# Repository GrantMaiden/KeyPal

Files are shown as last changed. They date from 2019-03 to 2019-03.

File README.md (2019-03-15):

KeyPal is A project I worked with during my undergrad alongside my teammates, Dane Le, Justin Warner, and Spencer Anderson.

I was the only EE working on the project, so my main duties were to develop the schematic and PCB for the group. I also developed the MCU application, and took care of component selection as well as analyzed and timing constraints on the system.

KeyPal is a fun solution to helping teach a new typist the ins and outs of proper keyboard hand placement.
It has capacitive sensors in the homerow of the keyboard, to make sure that proper hand placement is intact during typing, as well as multicolor LEDs under every key on the keyboard. These light up to aid the typist in learning the keypositions while using the peripheral typing trainer application, which is written in python.

________________________________________________________________________________________________________________________

Schematic creation, PCB layout, component selection, MCU design, C/C++, Python, timing analysis, Communication Protocols (i2c, USB),  capacitive touch.

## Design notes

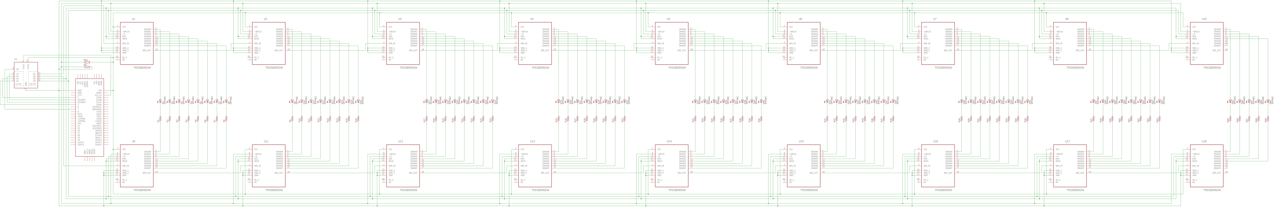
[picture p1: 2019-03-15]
Eagle/Projects/Keyboard PCB/Keyboard schematic.png

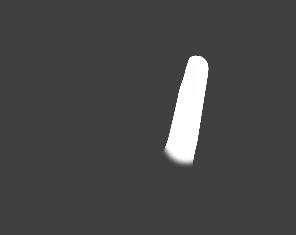
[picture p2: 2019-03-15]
Final/resources/finger_3.png

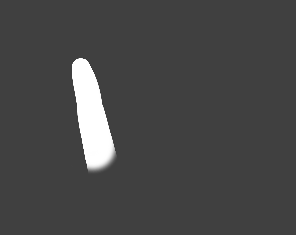
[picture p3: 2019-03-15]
Final/resources/finger_1.png

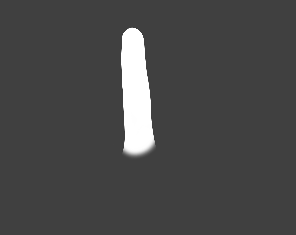
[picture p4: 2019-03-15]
Final/resources/finger_2.png

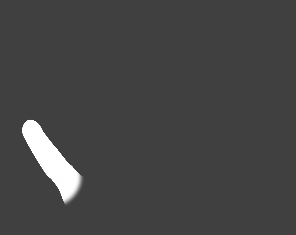
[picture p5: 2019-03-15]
Final/resources/finger_0.png

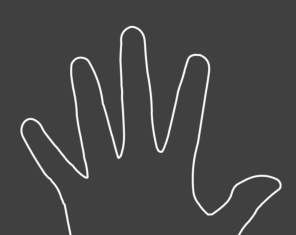
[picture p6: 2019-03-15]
Final/resources/hand_outline.png

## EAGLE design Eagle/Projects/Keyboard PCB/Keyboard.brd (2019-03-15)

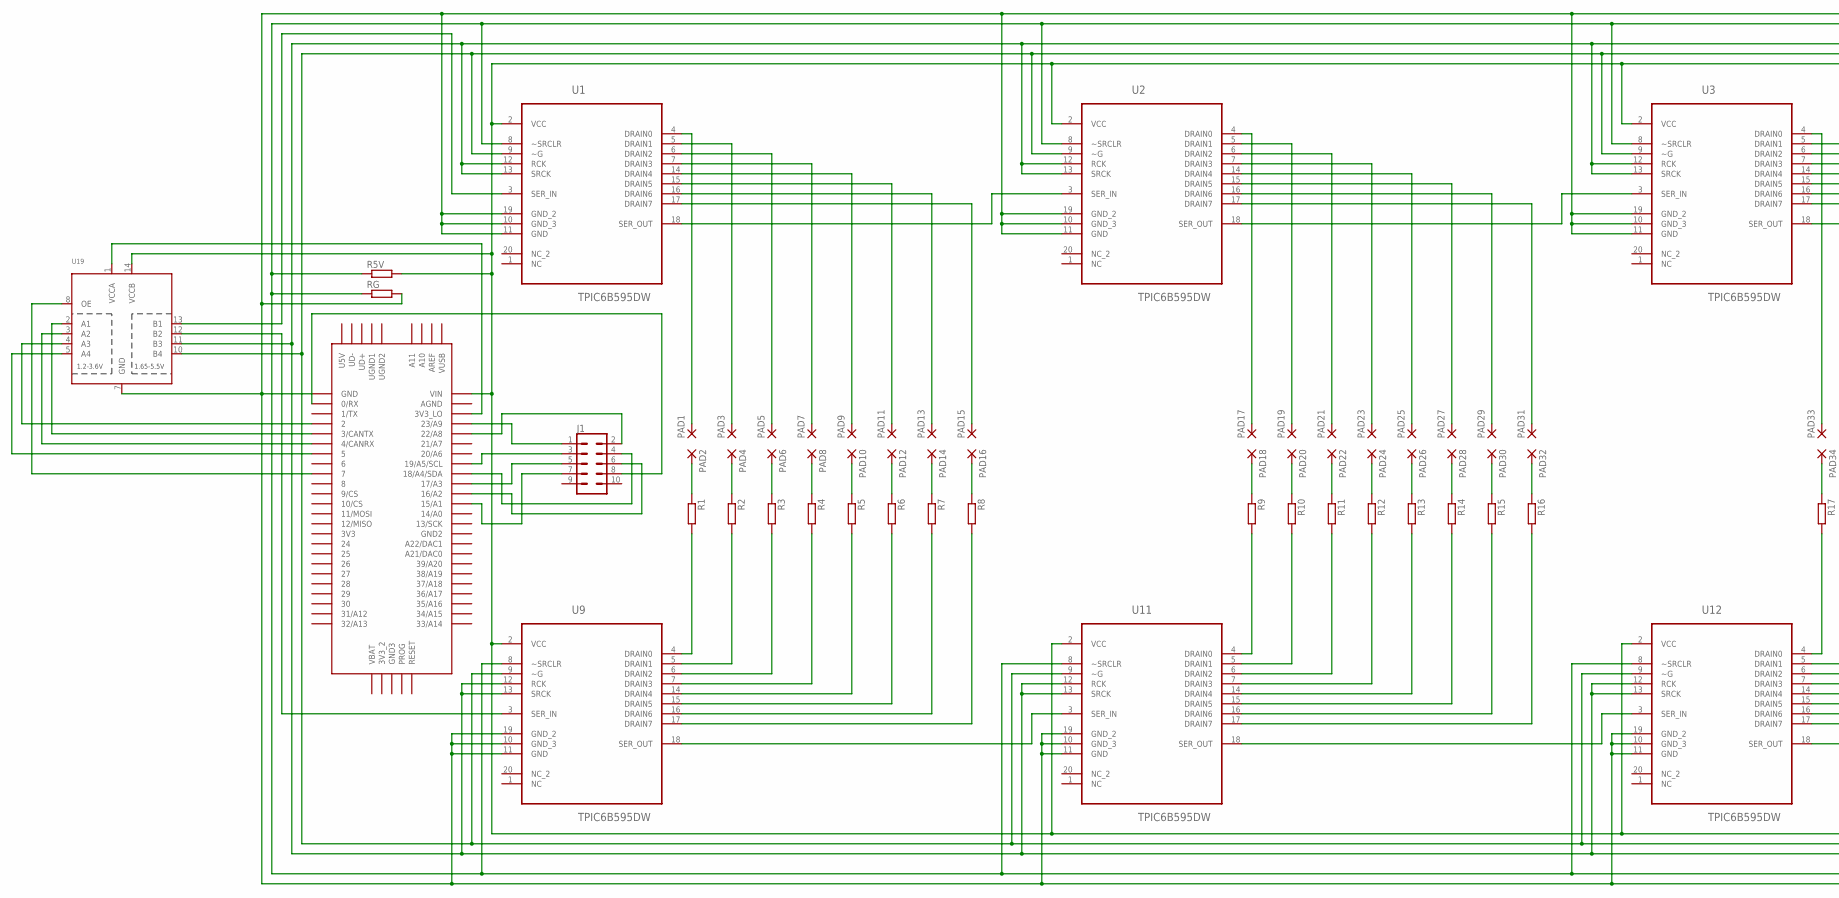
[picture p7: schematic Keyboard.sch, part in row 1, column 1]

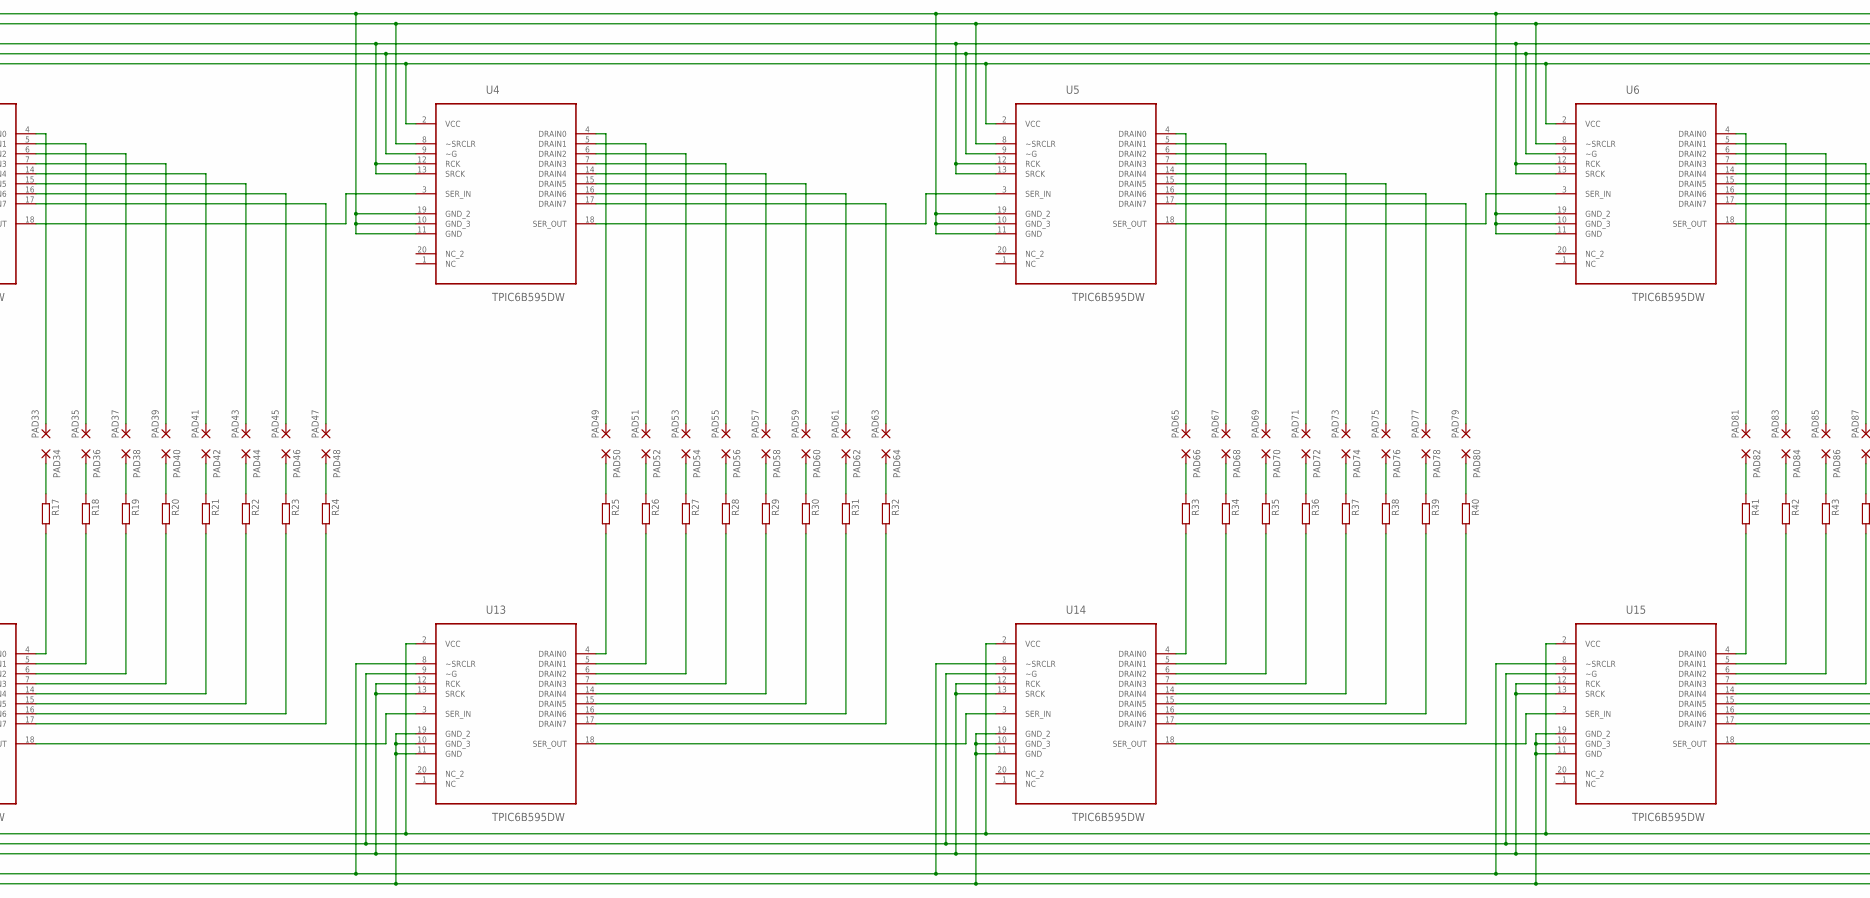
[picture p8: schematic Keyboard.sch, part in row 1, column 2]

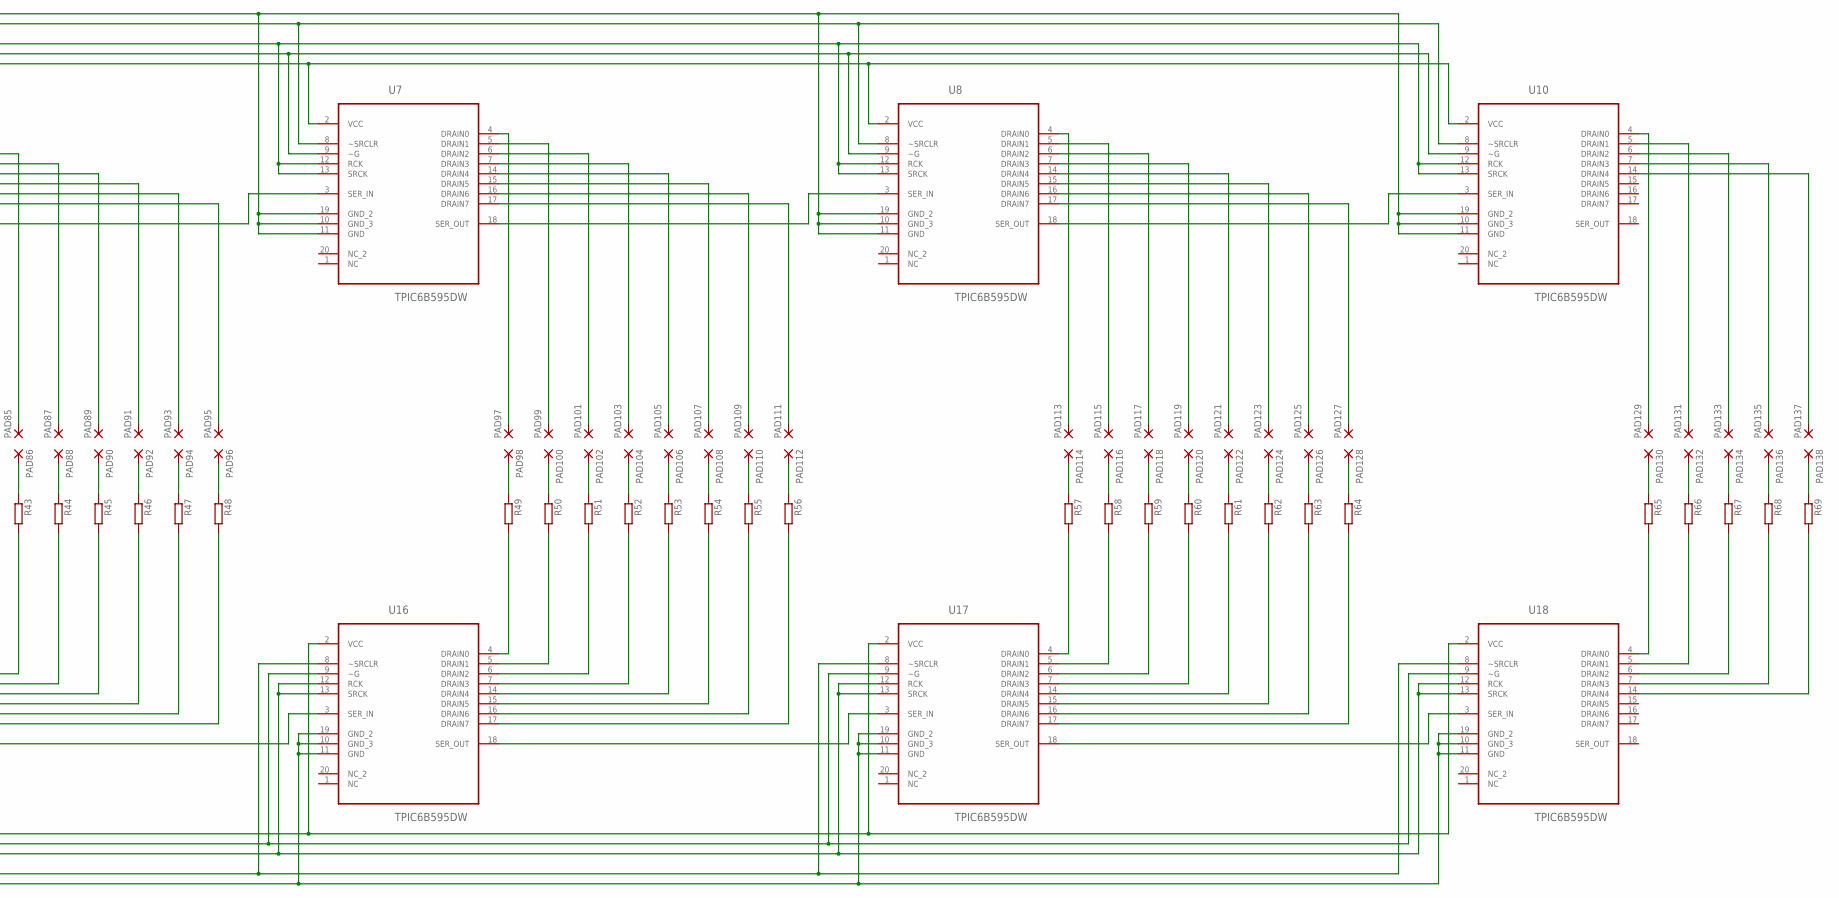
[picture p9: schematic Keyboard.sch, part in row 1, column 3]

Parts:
J1: CONN_05X2SHD; 2X5-SHROUDED
PAD1, PAD2, PAD3, PAD4, PAD5, PAD6, PAD7, PAD8, PAD9, PAD10, PAD11, PAD12, PAD13, PAD14, PAD15, PAD16, PAD17, PAD18, PAD19, PAD20, PAD21, PAD22, PAD23, PAD24, PAD25, PAD26, PAD27, PAD28, PAD29, PAD30, PAD31, PAD32, PAD33, PAD34, PAD35, PAD36, PAD37, PAD38, PAD39, PAD40, PAD41, PAD42, PAD43, PAD44, PAD45, PAD46, PAD47, PAD48, PAD49, PAD50, PAD51, PAD52, PAD53, PAD54, PAD55, PAD56, PAD57, PAD58, PAD59, PAD60, PAD61, PAD62, PAD63, PAD64, PAD65, PAD66, PAD67, PAD68, PAD69, PAD70, PAD71, PAD72, PAD73, PAD74, PAD75, PAD76, PAD77, PAD78, PAD79, PAD80, PAD81, PAD82, PAD83, PAD84, PAD85, PAD86, PAD87, PAD88, PAD89, PAD90, PAD91, PAD92, PAD93, PAD94, PAD95, PAD96, PAD97, PAD98, PAD99, PAD100, PAD101, PAD102, PAD103, PAD104, PAD105, PAD106, PAD107, PAD108, PAD109, PAD110, PAD111, PAD112, PAD113, PAD114, PAD115, PAD116, PAD117, PAD118, PAD119, PAD120, PAD121, PAD122, PAD123, PAD124, PAD125, PAD126, PAD127, PAD128, PAD129, PAD130, PAD131, PAD132, PAD133, PAD134, PAD135, PAD136, PAD137, PAD138: 1,6/0,8
R1, R2, R3, R4, R5, R5V, R6, R7, R8, R9, R10, R11, R12, R13, R14, R15, R16, R17, R18, R19, R20, R21, R22, R23, R24, R25, R26, R27, R28, R29, R30, R31, R32, R33, R34, R35, R36, R37, R38, R39, R40, R41, R42, R43, R44, R45, R46, R47, R48, R49, R50, R51, R52, R53, R54, R55, R56, R57, R58, R59, R60, R61, R62, R63, R64, R65, R66, R67, R68, R69: R; R0805
RG: R; R0805
U1, U2, U3, U4, U5, U6, U7, U8, U9, U10, U11, U12, U13, U14, U15, U16, U17, U18: TPIC6B595DW; SOIC127P1030X265-20N
U19: TXB0104PWRSOIC14; SO14
U$59: TEENSY_3.5/3.6

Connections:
unnamed: PAD2.1, R1.1
unnamed: U1.18 (SER_OUT), U2.3 (SER_IN)
unnamed: U1.12 (RCK), U1.13 (SRCK), U2.12 (RCK), U2.13 (SRCK), U3.12 (RCK), U3.13 (SRCK), U4.12 (RCK), U4.13 (SRCK), U5.12 (RCK), U5.13 (SRCK), U6.12 (RCK), U6.13 (SRCK), U7.12 (RCK), U7.13 (SRCK), U8.12 (RCK), U8.13 (SRCK), U9.12 (RCK), U9.13 (SRCK), U10.12 (RCK), U10.13 (SRCK), U11.12 (RCK), U11.13 (SRCK), U12.12 (RCK), U12.13 (SRCK), U13.12 (RCK), U13.13 (SRCK), U14.12 (RCK), U14.13 (SRCK), U15.12 (RCK), U15.13 (SRCK), U16.12 (RCK), U16.13 (SRCK), U17.12 (RCK), U17.13 (SRCK), U18.12 (RCK), U18.13 (SRCK), U19.11 (B3)
unnamed: PAD4.1, R2.1
unnamed: PAD6.1, R3.1
unnamed: PAD8.1, R4.1
unnamed: PAD10.1, R5.1
unnamed: PAD12.1, R6.1
unnamed: PAD14.1, R7.1
unnamed: PAD16.1, R8.1
unnamed: PAD18.1, R9.1
unnamed: U1.9 (~G), U2.9 (~G), U3.9 (~G), U4.9 (~G), U5.9 (~G), U6.9 (~G), U7.9 (~G), U8.9 (~G), U9.9 (~G), U10.9 (~G), U11.9 (~G), U12.9 (~G), U13.9 (~G), U14.9 (~G), U15.9 (~G), U16.9 (~G), U17.9 (~G), U18.9 (~G), U19.10 (B4)
unnamed: PAD20.1, R10.1
unnamed: PAD22.1, R11.1
unnamed: PAD24.1, R12.1
unnamed: PAD26.1, R13.1
unnamed: PAD28.1, R14.1
unnamed: PAD30.1, R15.1
unnamed: PAD32.1, R16.1
unnamed: PAD34.1, R17.1
unnamed: PAD36.1, R18.1
unnamed: PAD38.1, R19.1
unnamed: PAD40.1, R20.1
unnamed: PAD42.1, R21.1
unnamed: PAD44.1, R22.1
unnamed: PAD46.1, R23.1
unnamed: PAD48.1, R24.1
unnamed: PAD50.1, R25.1
unnamed: PAD52.1, R26.1
unnamed: PAD54.1, R27.1
unnamed: PAD56.1, R28.1
unnamed: PAD58.1, R29.1
unnamed: PAD60.1, R30.1
unnamed: PAD62.1, R31.1
unnamed: PAD64.1, R32.1
unnamed: PAD66.1, R33.1
unnamed: PAD68.1, R34.1
unnamed: PAD70.1, R35.1
unnamed: PAD72.1, R36.1
unnamed: PAD74.1, R37.1
unnamed: PAD76.1, R38.1
unnamed: PAD78.1, R39.1
unnamed: PAD80.1, R40.1
unnamed: PAD82.1, R41.1
unnamed: PAD84.1, R42.1
unnamed: PAD86.1, R43.1
unnamed: PAD88.1, R44.1
unnamed: PAD90.1, R45.1
unnamed: PAD92.1, R46.1
unnamed: PAD94.1, R47.1
unnamed: PAD96.1, R48.1
unnamed: PAD98.1, R49.1
unnamed: PAD100.1, R50.1
unnamed: PAD102.1, R51.1
unnamed: PAD104.1, R52.1
unnamed: PAD106.1, R53.1
unnamed: PAD108.1, R54.1
unnamed: PAD110.1, R55.1
unnamed: PAD112.1, R56.1
unnamed: PAD114.1, R57.1
unnamed: R5V.2, U1.2 (VCC), U2.2 (VCC), U3.2 (VCC), U4.2 (VCC), U5.2 (VCC), U6.2 (VCC), U7.2 (VCC), U8.2 (VCC), U9.2 (VCC), U10.2 (VCC), U11.2 (VCC), U12.2 (VCC), U13.2 (VCC), U14.2 (VCC), U15.2 (VCC), U16.2 (VCC), U17.2 (VCC), U18.2 (VCC), U19.14 (VCCB), U$59.VIN
unnamed: U19.4 (A3), U$59.2
unnamed: R5V.1, RG.1, U1.8 (~SRCLR), U2.8 (~SRCLR), U3.8 (~SRCLR), U4.8 (~SRCLR), U5.8 (~SRCLR), U6.8 (~SRCLR), U7.8 (~SRCLR), U8.8 (~SRCLR), U9.8 (~SRCLR), U10.8 (~SRCLR), U11.8 (~SRCLR), U12.8 (~SRCLR), U13.8 (~SRCLR), U14.8 (~SRCLR), U15.8 (~SRCLR), U16.8 (~SRCLR), U17.8 (~SRCLR), U18.8 (~SRCLR)
unnamed: U1.3 (SER_IN), U19.13 (B1)
unnamed: U2.18 (SER_OUT), U3.3 (SER_IN)
unnamed: R68.2, U18.7 (DRAIN3)
unnamed: R69.2, U18.14 (DRAIN4)
unnamed: PAD129.1, U10.4 (DRAIN0)
unnamed: PAD131.1, U10.5 (DRAIN1)
unnamed: U3.18 (SER_OUT), U4.3 (SER_IN)
unnamed: U4.18 (SER_OUT), U5.3 (SER_IN)
unnamed: U5.18 (SER_OUT), U6.3 (SER_IN)
unnamed: U6.18 (SER_OUT), U7.3 (SER_IN)
unnamed: U7.18 (SER_OUT), U8.3 (SER_IN)
unnamed: U8.18 (SER_OUT), U10.3 (SER_IN)
unnamed: U19.1 (VCCA), U$59.3V3_LO
unnamed: U19.2 (A1), U$59.3/CANTX
unnamed: U9.3 (SER_IN), U19.12 (B2)
unnamed: U19.8 (OE), U$59.7
unnamed: PAD116.1, R58.1
unnamed: PAD118.1, R59.1
unnamed: PAD120.1, R60.1
unnamed: PAD122.1, R61.1
unnamed: PAD124.1, R62.1
unnamed: PAD126.1, R63.1
unnamed: PAD128.1, R64.1
unnamed: U9.18 (SER_OUT), U11.3 (SER_IN)
unnamed: U11.18 (SER_OUT), U12.3 (SER_IN)
unnamed: U12.18 (SER_OUT), U13.3 (SER_IN)
unnamed: U13.18 (SER_OUT), U14.3 (SER_IN)
unnamed: U14.18 (SER_OUT), U15.3 (SER_IN)
unnamed: U15.18 (SER_OUT), U16.3 (SER_IN)
unnamed: U16.18 (SER_OUT), U17.3 (SER_IN)
unnamed: U17.18 (SER_OUT), U18.3 (SER_IN)
unnamed: RG.2, U1.10 (GND_3), U1.11 (GND), U1.19 (GND_2), U2.10 (GND_3), U2.11 (GND), U2.19 (GND_2), U3.10 (GND_3), U3.11 (GND), U3.19 (GND_2), U4.10 (GND_3), U4.11 (GND), U4.19 (GND_2), U5.10 (GND_3), U5.11 (GND), U5.19 (GND_2), U6.10 (GND_3), U6.11 (GND), U6.19 (GND_2), U7.10 (GND_3), U7.11 (GND), U7.19 (GND_2), U8.10 (GND_3), U8.11 (GND), U8.19 (GND_2), U9.10 (GND_3), U9.11 (GND), U9.19 (GND_2), U10.10 (GND_3), U10.11 (GND), U10.19 (GND_2), U11.10 (GND_3), U11.11 (GND), U11.19 (GND_2), U12.10 (GND_3), U12.11 (GND), U12.19 (GND_2), U13.10 (GND_3), U13.11 (GND), U13.19 (GND_2), U14.10 (GND_3), U14.11 (GND), U14.19 (GND_2), U15.10 (GND_3), U15.11 (GND), U15.19 (GND_2), U16.10 (GND_3), U16.11 (GND), U16.19 (GND_2), U17.10 (GND_3), U17.11 (GND), U17.19 (GND_2), U18.10 (GND_3), U18.11 (GND), U18.19 (GND_2), U19.7 (GND), U$59.GND
unnamed: U19.5 (A4), U$59.5
unnamed: PAD130.1, R65.1
unnamed: PAD1.1, U1.4 (DRAIN0)
unnamed: PAD3.1, U1.5 (DRAIN1)
unnamed: PAD5.1, U1.6 (DRAIN2)
unnamed: PAD7.1, U1.7 (DRAIN3)
unnamed: PAD9.1, U1.14 (DRAIN4)
unnamed: PAD11.1, U1.15 (DRAIN5)
unnamed: PAD13.1, U1.16 (DRAIN6)
unnamed: PAD15.1, U1.17 (DRAIN7)
unnamed: R1.2, U9.4 (DRAIN0)
unnamed: R2.2, U9.5 (DRAIN1)
unnamed: R3.2, U9.6 (DRAIN2)
unnamed: R4.2, U9.7 (DRAIN3)
unnamed: R5.2, U9.14 (DRAIN4)
unnamed: R6.2, U9.15 (DRAIN5)
unnamed: R7.2, U9.16 (DRAIN6)
unnamed: R8.2, U9.17 (DRAIN7)
unnamed: R9.2, U11.4 (DRAIN0)
unnamed: R10.2, U11.5 (DRAIN1)
unnamed: R11.2, U11.6 (DRAIN2)
unnamed: R12.2, U11.7 (DRAIN3)
unnamed: R13.2, U11.14 (DRAIN4)
unnamed: R14.2, U11.15 (DRAIN5)
unnamed: R15.2, U11.16 (DRAIN6)
unnamed: R16.2, U11.17 (DRAIN7)
unnamed: PAD17.1, U2.4 (DRAIN0)
unnamed: PAD19.1, U2.5 (DRAIN1)
unnamed: PAD21.1, U2.6 (DRAIN2)
unnamed: PAD23.1, U2.7 (DRAIN3)
unnamed: PAD25.1, U2.14 (DRAIN4)
unnamed: PAD27.1, U2.15 (DRAIN5)
unnamed: PAD29.1, U2.16 (DRAIN6)
unnamed: PAD31.1, U2.17 (DRAIN7)
unnamed: PAD33.1, U3.4 (DRAIN0)
unnamed: PAD35.1, U3.5 (DRAIN1)
unnamed: PAD37.1, U3.6 (DRAIN2)
unnamed: PAD39.1, U3.7 (DRAIN3)
unnamed: PAD41.1, U3.14 (DRAIN4)
unnamed: PAD43.1, U3.15 (DRAIN5)
unnamed: PAD45.1, U3.16 (DRAIN6)
unnamed: PAD47.1, U3.17 (DRAIN7)
unnamed: R17.2, U12.4 (DRAIN0)
unnamed: R18.2, U12.5 (DRAIN1)
unnamed: R19.2, U12.6 (DRAIN2)
unnamed: R20.2, U12.7 (DRAIN3)
unnamed: R21.2, U12.14 (DRAIN4)
unnamed: R22.2, U12.15 (DRAIN5)
unnamed: R23.2, U12.16 (DRAIN6)
unnamed: R24.2, U12.17 (DRAIN7)
unnamed: R25.2, U13.4 (DRAIN0)
unnamed: R26.2, U13.5 (DRAIN1)
unnamed: R27.2, U13.6 (DRAIN2)
unnamed: U19.3 (A2), U$59.4/CANRX
unnamed: R28.2, U13.7 (DRAIN3)
unnamed: R29.2, U13.14 (DRAIN4)
unnamed: R30.2, U13.15 (DRAIN5)
unnamed: R31.2, U13.16 (DRAIN6)
unnamed: R32.2, U13.17 (DRAIN7)
unnamed: PAD49.1, U4.4 (DRAIN0)
unnamed: PAD51.1, U4.5 (DRAIN1)
unnamed: PAD53.1, U4.6 (DRAIN2)
unnamed: PAD55.1, U4.7 (DRAIN3)
unnamed: PAD57.1, U4.14 (DRAIN4)
unnamed: PAD59.1, U4.15 (DRAIN5)
unnamed: PAD61.1, U4.16 (DRAIN6)
unnamed: PAD63.1, U4.17 (DRAIN7)
unnamed: PAD65.1, U5.4 (DRAIN0)
unnamed: PAD67.1, U5.5 (DRAIN1)
unnamed: PAD69.1, U5.6 (DRAIN2)
unnamed: PAD71.1, U5.7 (DRAIN3)
unnamed: PAD73.1, U5.14 (DRAIN4)
unnamed: PAD75.1, U5.15 (DRAIN5)
unnamed: PAD77.1, U5.16 (DRAIN6)
unnamed: PAD79.1, U5.17 (DRAIN7)
unnamed: R33.2, U14.4 (DRAIN0)
unnamed: R34.2, U14.5 (DRAIN1)
unnamed: R35.2, U14.6 (DRAIN2)
unnamed: R36.2, U14.7 (DRAIN3)
unnamed: R37.2, U14.14 (DRAIN4)
unnamed: R38.2, U14.15 (DRAIN5)
unnamed: R39.2, U14.16 (DRAIN6)
unnamed: R40.2, U14.17 (DRAIN7)
unnamed: R41.2, U15.4 (DRAIN0)
unnamed: R42.2, U15.5 (DRAIN1)
unnamed: R43.2, U15.6 (DRAIN2)
unnamed: R44.2, U15.7 (DRAIN3)
unnamed: R45.2, U15.14 (DRAIN4)
unnamed: R46.2, U15.15 (DRAIN5)
unnamed: R47.2, U15.16 (DRAIN6)
unnamed: R48.2, U15.17 (DRAIN7)
unnamed: PAD81.1, U6.4 (DRAIN0)
unnamed: PAD83.1, U6.5 (DRAIN1)
unnamed: PAD85.1, U6.6 (DRAIN2)
unnamed: PAD87.1, U6.7 (DRAIN3)
unnamed: PAD89.1, U6.14 (DRAIN4)
unnamed: PAD91.1, U6.15 (DRAIN5)
unnamed: PAD93.1, U6.16 (DRAIN6)
unnamed: PAD95.1, U6.17 (DRAIN7)
unnamed: R49.2, U16.4 (DRAIN0)
unnamed: R50.2, U16.5 (DRAIN1)
unnamed: R51.2, U16.6 (DRAIN2)
unnamed: R52.2, U16.7 (DRAIN3)
unnamed: R53.2, U16.14 (DRAIN4)
unnamed: R54.2, U16.15 (DRAIN5)
unnamed: R55.2, U16.16 (DRAIN6)
unnamed: R56.2, U16.17 (DRAIN7)
unnamed: PAD97.1, U7.4 (DRAIN0)
unnamed: PAD99.1, U7.5 (DRAIN1)
unnamed: PAD101.1, U7.6 (DRAIN2)
unnamed: PAD103.1, U7.7 (DRAIN3)
unnamed: PAD105.1, U7.14 (DRAIN4)
unnamed: PAD107.1, U7.15 (DRAIN5)
unnamed: PAD109.1, U7.16 (DRAIN6)
unnamed: PAD111.1, U7.17 (DRAIN7)
unnamed: PAD113.1, U8.4 (DRAIN0)
unnamed: PAD115.1, U8.5 (DRAIN1)
unnamed: PAD117.1, U8.6 (DRAIN2)
unnamed: PAD119.1, U8.7 (DRAIN3)
unnamed: PAD121.1, U8.14 (DRAIN4)
unnamed: PAD123.1, U8.15 (DRAIN5)
unnamed: PAD125.1, U8.16 (DRAIN6)
unnamed: PAD127.1, U8.17 (DRAIN7)
unnamed: R57.2, U17.4 (DRAIN0)
unnamed: R58.2, U17.5 (DRAIN1)
unnamed: R59.2, U17.6 (DRAIN2)
unnamed: R60.2, U17.7 (DRAIN3)
unnamed: R61.2, U17.14 (DRAIN4)
unnamed: R62.2, U17.15 (DRAIN5)
unnamed: R63.2, U17.16 (DRAIN6)
unnamed: R64.2, U17.17 (DRAIN7)
unnamed: R65.2, U18.4 (DRAIN0)
unnamed: R66.2, U18.5 (DRAIN1)
unnamed: R67.2, U18.6 (DRAIN2)
unnamed: PAD132.1, R66.1
unnamed: PAD134.1, R67.1
unnamed: PAD136.1, R68.1
unnamed: PAD138.1, R69.1
unnamed: PAD133.1, U10.6 (DRAIN2)
unnamed: PAD135.1, U10.7 (DRAIN3)
unnamed: PAD137.1, U10.14 (DRAIN4)
unnamed: J1.1, U$59.23/A9
unnamed: J1.2, U$59.22/A8
unnamed: J1.3, U$59.19/A5/SCL
unnamed: J1.4, U$59.18/A4/SDA
unnamed: J1.5, U$59.17/A3
unnamed: J1.6, U$59.16/A2
unnamed: J1.7, U$59.15/A1
unnamed: J1.8, U$59.0/RX

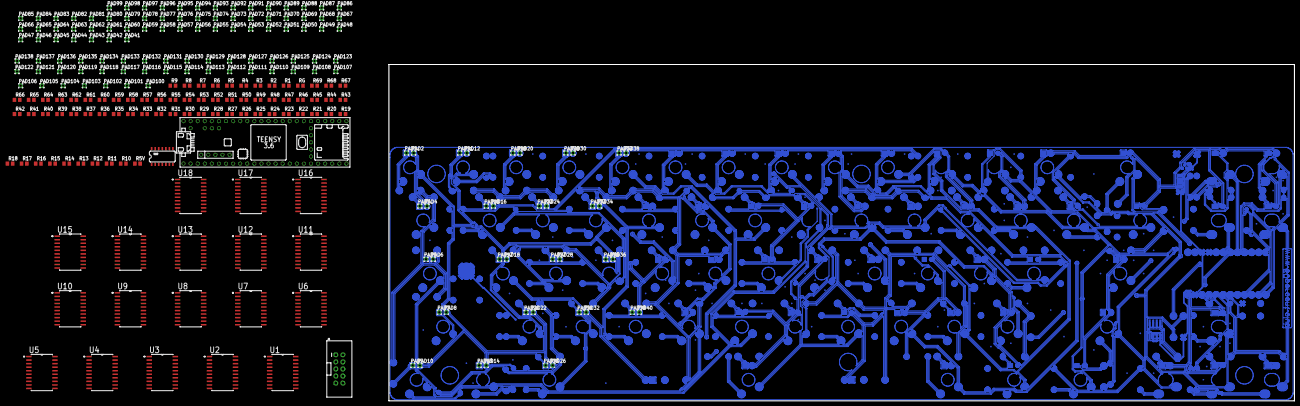
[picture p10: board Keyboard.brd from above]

Board: 2 copper layers, 324.8 x 120.6 mm, 230 parts (0 on the bottom side), 244 nets.

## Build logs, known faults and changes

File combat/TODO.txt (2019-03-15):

Refactorings:
  Instead of random-assed properties on a class, classes should have hashes called "images" and "anims"
  Maybe a common base class starts those as {} and autoloads loadImages for that class on first instantiation.

Easy stuff:
  Static feeders and dictionary powerups that temporarily switch to those wordsets

Quick Fixes:
  That weird hop when you fall down from a height.
  Powerup fall animation
  Score header stuff is disapeering for no reason.
  Point values when you score would be nice... maybe something too to indicate miss
  Regular soldiers pain anim doesn't show? I didn't do it :P
  The way animations are loaded is as i recall shitty and probalu shows bad knowlege of python

DEBUGGERS:
    Jumping debugger - fixed set of platforms to show edge-cases for jumping, jump-pathfinding without enemies.
    Feed debugger - show original content, sentences, words
    Animation debugger - display individual animations all on one screen, for easy design replacement

Challenge Screen
  Enable words to be shown on challenge screen and typed on
  Let a wordbuilder be sent into challenge
  Fix feeds to get sentences

Architecture
  Make an EventManager class ("Mediator") that parses events on tick and dispatches whatever signals
    need to be done depending on current scene.

Interface
  START/OPTIONS at beginning
      Options lets you set word source, other parameters
  SMB3 style world map to select stages?
      The most important part of making this would be it lets me abstract out some stuff with regard to what 'scene' is being drawn.

Bugs
  Player jump isn't as optimistic as it should be when jumping from ledge to ledge with an interrupt in ground inbetween.
  Word's draw function needs to have x really be centerx for multi-line sentences. Also comment that sucker.
  Fix int division bug with resolutions not divisible by 5/6
  Figure out how to use eclipse right
  Score row shitty updating bug
  Align updates to refresh rate to eliminate ugliness?
  Parabolic jump for such as enemies
  Better jump collision with edges; don't start falling after collision

General
  Make different "standard" levels on worldmap differentiable by platform texture?
  Footer with gems
  Options Screen
  Better randomly generated environs
  Image for platforms/better looking platforms
  Better backgrounds and tiles
  Reorganize images into sprite sheets? Or not, who cares.
  better graphic for platform edges
  player death anim! mega-man style asterisk explosion would be good.

Weapons
  Weapon Powerups
  Weapon Effects

Powerups
  Have powerups drop from enemies gracefully instead of hitting the ground instantly.
  Slowmo (Might require changing all tick() functions to take an "amount of time since last tick")

Enemies
  Commando enemy serves as sub-boss, lurks on his own platform, you need to get close to him to engage. Engagement results in TYPING CHALLENGE!$
  Make the soldier jump
  Or perhaps, subclass into not-jumping soldier (StrandedSoldier?) and jumping soldier
  Maybe: BasicSoldier (only falls), StrandedSoldier (scared of heights), JumpingSoldier (follows you)
  Pathfinding for chopper - probably pretty hard!
  Redo soldier falling collision
  A boss
  CHOPPER ALGORITHM: Move to the nearest hole in direction of player, traverse hole
  PRELIMINARY SOLDIER ALGORITHM: Jump at -every- oppurtunity.

Player
  Better AI jump algorithm: enable lateral jumps, make 'late jumps' more possible, make jump look more graceful in general
  Running from enemies? Or not.
  Death animation
  Platform queueing?
  shooting while jumping

Far Future
  Minigames
      Math minigame a-la brain age
      Backwards typing - two ways to do it
  Sound
  Multiplayer?

-- AI RULES --
Gameplay will normally consist of (automatically) running forward while stopping to type at enemies before they collide with you.
The player will have no control over the movement of the character other than periodic "choice words" that pop up, directing them to jump to a ledge, shoot a powerup etc
The player character will run forward unless doing so brings it straight into an enemy.
If there is an enemy ahead, the character will turn around to increase the distance between itself and the enemy.
Unless there is an enemy a shorter distance in the other direction. In which case the player will go into idle state until one of the two is destroyed.
Player's character will periodically stop for 'events', like bosses and minigames

Idea: explosive enemies detonate other nearby enemies when killed (you don't get word credit for those killed)

Idea: normal weapon freezes words in place
Idea: shotgun weapon blasts enemy backwards along shot vector
Idea: smart bomb kills all the enemies
Idea: fun to think about but hard to code - moving platform area where smart jumps still work

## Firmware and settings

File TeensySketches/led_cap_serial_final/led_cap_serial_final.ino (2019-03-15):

// Use this if you want debug messages
//#define DEBUG 1
// Use this to time each request handling
//#define TIMING 1

#ifdef DEBUG
  #define DEBUG_PRINTLN(x) debugSerial.println(x)
  #define DEBUG_PRINT(x) debugSerial.print(x)
  #define DEBUG_PRINTDEC(x) debugSerial.print(x, DEC)
#else
  #define DEBUG_PRINTLN(x)
  #define DEBUG_PRINT(x)
  #define DEBUG_PRINTDEC(x)
#endif

#ifdef TIMING
  unsigned long stime;
  #define TIMING_START(msg) stime = micros()
  #define TIMING_STOP() stime = micros() - stime; debugSerial.println(stime)
#else
  #define TIMING_START()
  #define TIMING_STOP()
#endif

const byte CMD_LEDS = 1;
const byte CMD_CAPS = 2;
const byte CMD_INIT = 3;
const byte ACK = 64;

const byte LED_OFF = 1;
const byte LED_GREEN = 2;
const byte LED_RED = 3;
const byte LED_ORANGE = 4;

const byte NUM_KEYS = 70;
byte leds[NUM_KEYS];
int leds_on = 0;

const byte NUM_CAPS = 8;
int cap_pins[] = {15, 18, 0, 16, 17, 19, 22, 23};
// Max value that touch sensor reads
const int DATA_CLAMP_VALUE = 65536;

// Store the maximum of the most recent readings
int cap_data[NUM_CAPS];

// 2D array to store intermediate reading results
int cap_readings[NUM_CAPS];
int cap_sensor_index = 0;

// Teensy hardware serial. RX: 9, TX: 10
#define debugSerial Serial2

//LEDs that are on counter
int ledsOn = 0;

void setup() {
  int i;
  // Set LED's initial state
  for (i = 0; i < NUM_KEYS; i++) {
    leds[i] = LED_OFF;
  }
  // Initialize the GPIO pins
  for (i = 1; i < 8; i++) {
    pinMode(i, OUTPUT);
  }
  for(i=60; i<69; i++){
    leds[i] = 2;
  }
  digitalWrite(7, HIGH); //Uncomment when using this sketch in PCB version
  // Acquire initial sensor readings
  for (i = 0; i < NUM_CAPS; i++) {
    updateSensorData();
  }
  // Setup the debug serial
  debugSerial.begin(9600);
  DEBUG_PRINTLN("Debugging");
  Serial.begin(115200);
}

void loop() {
  // Output Green state to shift registers
  digitalWrite(5, LOW); //Enable Output for Shift registers
  updateLEDState(LED_GREEN);
  // Delay and read next sensor
  beginDelay(5600);
  updateSensorData();
  endDelay();
  DutyCycleAdjust();
  digitalWrite(5, HIGH); //DISABLE Output for Shift registers
  // Delay and check for serial communication requests
  beginDelay(5000);
  updateSerial();
  endDelay();
  DutyCycleAdjust();
}

// Delay tools to allows functions to execute then wait for the remainder of a delay
int delayDelta;
int delayTime;
// Called before the function executes
void beginDelay(int delayMicros) {
  delayTime = delayMicros;
  delayDelta = micros();
}
// Called after to wait for the remaining time, if any
void endDelay() {
  delayDelta = micros() - delayDelta;
  if (delayDelta < delayTime)
    delayMicroseconds(delayTime - delayDelta);
  delayDelta = 0;
  delayTime = 0;
}

// Performs a sensor reading and updates the readings and data arrays
void updateSensorData() {
  // Get the next sensor reading
  cap_data[cap_sensor_index] = touchRead(cap_pins[cap_sensor_index]);
  // Update the index variables for the next iteration
  cap_sensor_index = (cap_sensor_index + 1) % NUM_CAPS;
}

// Updates the shift registers for an LED color based on the given flag
void updateLEDState(byte flag) {
  int i;
  for (i = 0; i < NUM_KEYS; i++){
    if (leds[i] == LED_GREEN){
      digitalWrite(4, HIGH);
      digitalWrite(3, LOW);
    } else {
      digitalWrite(4, LOW);
      digitalWrite(3, LOW);
    }
    digitalWrite(2, LOW);
    __asm__("nop\n\t""nop\n\t""nop\n\t""nop\n\t""nop\n\t""nop\n\t""nop\n\t""nop\n\t""nop\n\t""nop\n\t""nop\n\t""nop\n\t"); 
    digitalWrite(2, HIGH);
    __asm__("nop\n\t""nop\n\t""nop\n\t""nop\n\t""nop\n\t""nop\n\t""nop\n\t""nop\n\t""nop\n\t""nop\n\t""nop\n\t""nop\n\t");
  }
}

// Checks serial communication and performs and sending or receiving the client requests
void updateSerial() {
  int i;
  byte res = 0;
  if (Serial.available() > 0) {
    // Read the next command
    res = Serial.read();
    DEBUG_PRINTLN("Command code: ");
    DEBUG_PRINTDEC(res);
    DEBUG_PRINTLN();
    
    // Fork logic based on command
    if (res == CMD_LEDS) {
      // Update LED array values
      DEBUG_PRINTLN("Reading key data");
      leds_on = 0;
      for (i = 0; i < NUM_KEYS; i++) {
        leds[i] = Serial.read();
        if (leds[i] != LED_OFF)
          leds_on++;
      }
      DEBUG_PRINTLN("Done reading key data");
      Serial.write(ACK);
      
      // Print LED states for debugging
      #ifdef DEBUG
        for (i = 0; i < NUM_KEYS; i++) {
          DEBUG_PRINTDEC(leds[i]);
          DEBUG_PRINT(' ');
        }
        DEBUG_PRINTLN();
      #endif
    } else if (res == CMD_CAPS) {
      // Send sensor data
      DEBUG_PRINTLN("Sending sensor data");
      Serial.write(NUM_CAPS);
      for (i = 0; i < NUM_CAPS; i++) {
        DEBUG_PRINTDEC(cap_data[i]);
        DEBUG_PRINTLN();
        // clamp the sensor value into a byte
        Serial.write(map(cap_data[i], 0, DATA_CLAMP_VALUE, 0, 255));
      }
      Serial.write(ACK);
    } else if (res == CMD_INIT) {
      // Reset LED state and send ACK byte
      for (i = 0; i < NUM_KEYS; i++) {
        leds[i] = LED_OFF;
      }
      Serial.write(ACK);
    }
  }
}

void DutyCycleAdjust(){ //Decreases the effective duty cycle to prohibit damaging LEDS or drawing to much current.
//    if (ledsOn > 10){
//    digitalWrite(5, HIGH); //Disable Output for Shift registers
//    //delayMicroseconds(ledsOn*10); //Wait After Red State is set
//  }
}

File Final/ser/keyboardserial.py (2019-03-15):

import serial


## Teensy Vendor ID and Product ID
VID = "16C0"
PID = "0483"

## Command codes for the keyboard
CMD_LEDS = 1    # update the state of the leds
CMD_CAPS = 2    # retrieve the capacative sensor data
CMD_INIT = 3    # initiate a connection with the teensy
ACK = 64


BAUD = 115200

class KeyboardSerial:
    ## Keyboard information
    KEYS = ['ARROW_RIGHT', 'PG_DN', 'PG_UP', 'ARROW_DOWN', 'ARROW_UP', 'DEL', 'INS', 'ARROW_LEFT',
            '\\', 'BACKSPACE', 'ENTER', 'SHIFT_RIGHT', 'CTRL_RIGHT', ']', '=', '"', '[',
            'ALT_RIGHT', '/', '-', ';', 'p', '.', 'FN', '0', 'l', 'o', ',', '9', 'k', 'i', 'SPACE_RIGHT',
            'm', '8', 'j', 'u', 'n', '7', 'h', 'y', 'b', '6', 'g', 't', 'v', '5', 'f', 'SPACE_LEFT',
            'r', 'c', '4', 'd', 'e', 'x', '3', 's', 'ALT_LEFT', 'w', 'z', '2', 'a', 'q', 'WIN', '1', 'CTRL_LEFT',
            'SHIFT_LEFT', 'CAPSLOCK', 'TAB', 'ESC']
    CHAR_MAP = {'\\': 8, ']': 13, '=': 14, '\'': 15, '[': 16, '/': 18, '-': 19, ';': 20, 'p': 21, '.': 22, 'FN': 23, '0': 24,
            'l': 25, 'o': 26, ',': 27, '9': 28, 'k': 29, 'i': 30, 'm': 32, '8': 33, 'j': 34, 'u': 35, 'n': 36, '7': 37,
            'h': 38, 'y': 39, 'b': 40, '6': 41, 'g': 42, 't': 43, 'v': 44, '5': 45, 'f': 46, 'r': 48, 'c': 49, '4': 50,
            'd': 51, 'e': 52, 'x': 53, '3': 54, 's': 55, 'w': 57, 'z': 58, '2': 59, 'a': 60, 'q': 61, '1': 63}

    ## LED state values
    LED_OFF = 1
    LED_GREEN = 2
    LED_RED = 3
    LED_ORANGE = 4

    def __init__(self):
        self.key_states = [self.LED_OFF for led in range(len(self.KEYS))]
        self.ser = None

    def is_connected(self):
        return self.ser is not None and self.ser.is_open

    def connect(self, port):
        # Close any old connections
        if self.ser is not None:
            if self.ser.is_open:
                self.ser.close()
        # Opens a serial port with a 1s timeout
        try:
            self.ser = serial.Serial(port, baudrate=BAUD)
        except serial.SerialException:
            print("Failed to connect to port " + port)
            return False
        return True

    # Connect to the teensy automatically
    def autoconnect(self):
        # Close any old connections
        if self.ser is not None:
            if self.ser.is_open:
                self.ser.close()
        # Opens a serial port with a 1s timeout
        try:
            self.ser = serial.serial_for_url("hwgrep://" + VID + ":" + PID)
        except serial.SerialException:
            print("Failed to connect")
            return False
        return True

        

    def disconnect(self):
        if self.is_connected():
       	    self.ser.close()

    # Sends a byte over serial and waits for ACK byte
    def send(self, byte):
        if not self.is_connected():
            return False
        self.ser.write(bytes([byte]))
        return True

    # Sends an array of bytes
    def sendAll(self, data):
        if not self.is_connected():
            return False
        self.ser.write(bytes(data))
        return True

    # Take a dict of key->LED_STATE and sends the
    # updated state over the serial connection
    def update_leds(self, led_states):
        if not self.is_connected():
            return False
        # Write the command code and number of k,v pairs
        commands = [CMD_LEDS]
        # Update the internal key array
        for i, key in enumerate(self.KEYS):
            if key in led_states:
                self.key_states[i] = led_states[key]
        # Send the sequence of states
        # print("Sending state sequence of length " + str(len(self.KEYS)))
        for state in self.key_states:
            commands.append(state)
        self.sendAll(commands)
        # print("Waiting for ACK")
        # wait for an ACK byte before returning
        return self.ser.read() == bytes([ACK])
            
    def get_sensor_data(self):
        if not self.is_connected():
            return False
        # Write the command code
        self.send(CMD_CAPS)
        # Get the number of sensors
        sensor_len = int.from_bytes(self.ser.read(), byteorder='big')
        sensors = []
        for i in range(sensor_len):
            cap_data = int.from_bytes(self.ser.read(), byteorder='big')
            sensors.append(cap_data)
        if self.ser.read() != bytes([ACK]):
            print("Expected ACK after reading sensors")
            return False
        return sensors

    def clear_leds(self):
        if not self.is_connected():
            return False
        clear_states = {}
        for key in self.KEYS:
            clear_states[key] = self.LED_OFF
        self.update_leds(clear_states)
        return True

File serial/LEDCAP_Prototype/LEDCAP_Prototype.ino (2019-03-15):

/*
  LED & CAPACITANCE CONTROL MODULE
*/

 // Use this if you want debug messages
#define DEBUG 1
// Use this to time each request handling
//#define TIMING 1

#ifdef DEBUG
  #define DEBUG_PRINTLN(x) debugSerial.println(x); debugSerial.println()
  #define DEBUG_PRINT(x) debugSerial.print(x)
  #define DEBUG_PRINTDEC(x) debugSerial.print(x, DEC)
#else
  #define DEBUG_PRINTLN(x)
  #define DEBUG_PRINT(x)
  #define DEBUG_PRINTDEC(x)
#endif

const byte CMD_LEDS = 1;
const byte CMD_CAPS = 2;
const byte ACK = 64;
const byte NUM_KEYS = 70;
const byte NUM_CAPS = 8;

const byte LED_OFF = 1;
const byte LED_GREEN = 2;
const byte LED_RED = 3;
const byte LED_ORANGE = 4;

byte leds[NUM_KEYS];

int cap_pins[] = {4, 5};


// Teensy hardware serial. RX: 9, TX: 10
#define debugSerial Serial2

// Global Variables
int ledArray[69];
int count;
int ledsOn = 0; // Number of LEDS that are currently consuming Current

// For the sensor delay
const int numReadings = 5;
int readings[numReadings*8];
int readIndex = 0;
int sensorCount = 0;

// sensor data
int sensorValues[8];

void setup() { 
  int i;
  // Setup the debug serials
  debugSerial.begin(9600);
  DEBUG_PRINTLN("Debugging");
  Serial.begin(115200);
  while (!Serial) {
    ;
  }
  DEBUG_PRINTLN("Connected to client");               

  // TEST CODE FOR LED INITALIAZATION
  /* 
  for(i=0; i<69; i++){
    ledArray[i] = 0;
  }
  ledArray[60] = 1;
  for(i=67; i<69; i++){
    ledArray[i] = 1;
  } 
  for(i=65; i<67; i++){
    ledArray[i] = 2;
  } 
  */
  for(i=0; i<69; i++){
    ledArray[i] = LED_OFF;
  } 
  
  PinSetup(); //Setup Teensy Pins
  //digitalWrite(7, LOW); //Uncomment when using this sketch in PCB version
  for (int thisReading = 0; thisReading < numReadings*8; thisReading++) { // Get Capacitance Sensor Data
    AcquireCapacitance(1);
  }
}

void loop() {
  
  //Output GREEN STATE (1) to shift registers
  GreenState();
  AcquireCapacitance(5600); // Read Capacitance values
  DutyCycleAdjust(); //Duty Cycle Adjustment delay (further testing required -> what is max amperage draw possible from usb?)

  //Output RED STATE (2) to shift registers
  RedState();
  delayMicroseconds(4800); //Duty Cycle Delay For Red State
  DutyCycleAdjust();
  updateSerial();
}

void PinSetup(){
  for (int i = 1; i < 8; i++) {
    pinMode(i, OUTPUT);
  }
}

void AcquireCapacitance (int timer) { // Reads Capacitance from keys. Reads ONE key each time through main program loop. This stops timing issues (capacitance reading takes a long time)
  int deltat = micros();
  
  switch (sensorCount) {
    case 0: 
    readings[readIndex + sensorCount * numReadings] = touchRead(23);
    sensorValues[7] = findMax(sensorCount * numReadings);
    //Serial.println(sensorData1);
    break;
    case 1: 
    readings[readIndex + sensorCount * numReadings] = touchRead(22);
    sensorValues[6] = findMax(sensorCount * numReadings);
    //Serial.println(sensorData2);
    break;
    case 2: 
    readings[readIndex + sensorCount * numReadings] = touchRead(19);
    sensorValues[5] = findMax(sensorCount * numReadings);
    //Serial.println(sensorData3);
    break;
    case 3: 
    readings[readIndex + sensorCount * numReadings] = touchRead(18);
    sensorValues[1] = findMax(sensorCount * numReadings);
    //Serial.println(sensorData4);
    break;
    case 4: 
    readings[readIndex + sensorCount * numReadings] = touchRead(17);
    sensorValues[4] = findMax(sensorCount * numReadings);
    //Serial.println(sensorData5);
    break;
    case 5: 
    readings[readIndex + sensorCount * numReadings] = touchRead(16);
    sensorValues[0] = findMax(sensorCount * numReadings);
    //Serial.println(sensorData6);
    break;
    case 6: 
    readings[readIndex + sensorCount * numReadings] = touchRead(15);
    sensorValues[3] = findMax(sensorCount * numReadings);
    //Serial.println(sensorData7);
    break;
    case 7: 
    readings[readIndex + sensorCount * numReadings] = touchRead(0);
    sensorValues[2] = findMax(sensorCount * numReadings);
    //Serial.println(sensorData8);
    break;
  }
  // advance to the next position in the array:
  if (sensorCount >= 7) {
    readIndex = readIndex + 1;
    sensorCount = 0;
  } else
    sensorCount = sensorCount + 1;

  // if we're at the end of the array...
  if (readIndex >= numReadings) {
    // ...wrap around to the beginning:
    readIndex = 0;
  }

  deltat = micros() - deltat;
  //Serial.println(deltat);
  //Serial.println();
  if (deltat < timer) {
    delayMicroseconds(timer - deltat);
  }
}

int findMax(int startpos) {
  int maxNum = 0;
  int i;
  for (i = startpos; i < startpos + 5; i++) {
    if (readings[i] > maxNum)
      maxNum = readings[i];
  }
  return maxNum;
}

void GreenState(){
  int i;
  digitalWrite(5, HIGH); //Disable Output for Shift registers
  for (i = 0; i<70; i++){
    if (ledArray[i] > 0){ //Count number of LEDS that are ON.
      ledsOn = ledsOn + 1;
    }
    if (ledArray[i] == LED_GREEN || ledArray[i] == LED_ORANGE){
      digitalWrite(2, LOW);
      digitalWrite(3, HIGH);
    }
    else{
      digitalWrite(2, LOW);
      digitalWrite(3, LOW);
    }
    digitalWrite(4, LOW);
    __asm__("nop\n\t""nop\n\t""nop\n\t""nop\n\t""nop\n\t""nop\n\t""nop\n\t""nop\n\t""nop\n\t""nop\n\t""nop\n\t""nop\n\t"); 
    digitalWrite(4, HIGH);
    __asm__("nop\n\t""nop\n\t""nop\n\t""nop\n\t""nop\n\t""nop\n\t""nop\n\t""nop\n\t""nop\n\t""nop\n\t""nop\n\t""nop\n\t");
  }
  digitalWrite(5, LOW); //Enable Output for Shift registers
}

void RedState(){
  int i;
  digitalWrite(5, HIGH); //Disable Output for Shift registers
  for (i = 0; i<70; i++){
    if (ledArray[i] == LED_RED || ledArray[i] == LED_ORANGE){
      digitalWrite(2, HIGH);
      digitalWrite(3, LOW);
      //Serial.write("test");
    }
    else{
      digitalWrite(2, LOW);
      digitalWrite(3, LOW);
    }
    digitalWrite(4, LOW);
    __asm__("nop\n\t""nop\n\t""nop\n\t""nop\n\t""nop\n\t""nop\n\t""nop\n\t""nop\n\t""nop\n\t""nop\n\t""nop\n\t""nop\n\t");
    digitalWrite(4, HIGH);
    __asm__("nop\n\t""nop\n\t""nop\n\t""nop\n\t""nop\n\t""nop\n\t""nop\n\t""nop\n\t""nop\n\t""nop\n\t""nop\n\t""nop\n\t");
  }
  digitalWrite(5, LOW); //Enable Output for Shift registers
}

void DutyCycleAdjust(){ //Decreases the effective duty cycle to prohibit damaging LEDS or drawing to much current.
//    if (ledsOn > 10){
//    digitalWrite(5, HIGH); //Disable Output for Shift registers
//    //delayMicroseconds(ledsOn*10); //Wait After Red State is set
//  }
}


byte res = 0;
int i;
int capValue = 0;
unsigned long stime;
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

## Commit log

2019-03-15 Bulk Upload
    [words.csv]
2019-03-15 Update Eagle Keyboard Files
    [Keyboard.brd, Keyboard.sch, untitled.brd]

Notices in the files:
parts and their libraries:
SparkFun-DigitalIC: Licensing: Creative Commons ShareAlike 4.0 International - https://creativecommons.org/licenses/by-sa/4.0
